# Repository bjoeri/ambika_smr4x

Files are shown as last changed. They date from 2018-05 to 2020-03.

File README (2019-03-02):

SMR4X - Mutated Ambika SMR-4 voice card

SMR4X is a mutation of the original Ambika SMR-4 voice card with an additional mash up of various other design modifications:
- Added programmable 4P/2P filter slope selection (ported from SMR-4-Pi but with added decoupling capacitors for the 4052 and excluding the 1P/3P slopes)
- Added programmable full bandwidth resonance compensation by optional bypass of capacitor in feedback (inspired by Shruthi-1 Sound Designer Edition). NOTE: FOR SOME REASON THIS DOESN'T APPEAR TO MAKE ANY SIGNIFICANT DIFFERENCE, SEE https://forum.mutable-instruments.net/t/another-modified-ambika-smr-4-voice-card/
- Added 50k trimpot and modified related resistor value (from 150k to 120k) to allow for filter tuning (ported from SMR4-Plus)

==============================================
WARNING: THIS IS INCOMPLETE WORKS IN PROGRESS! 
==============================================

SMR4X is released under cc-by-sa 4.0 license.

Original design of the official SMR4 voice card by E. Gillet (pichenettes@mutable-instruments.net).

This design by Björn Somell (bjoeri@gmail.com) relies heavily on the original design, and is inspired by modifications from SMR-4-Pi voice card by Pharmasonic (https://github.com/Pharmasonic/SMR-4-Pi), Shruthi-1 Sound Designer Edition by Martin Walkers (http://mutable-instruments-archive.net/wiki/Shruthi-1_SDE), and SMR4-Plus voice card by Andre Laska (kontakt@tubeohm.com)

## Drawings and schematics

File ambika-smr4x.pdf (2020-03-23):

A

A

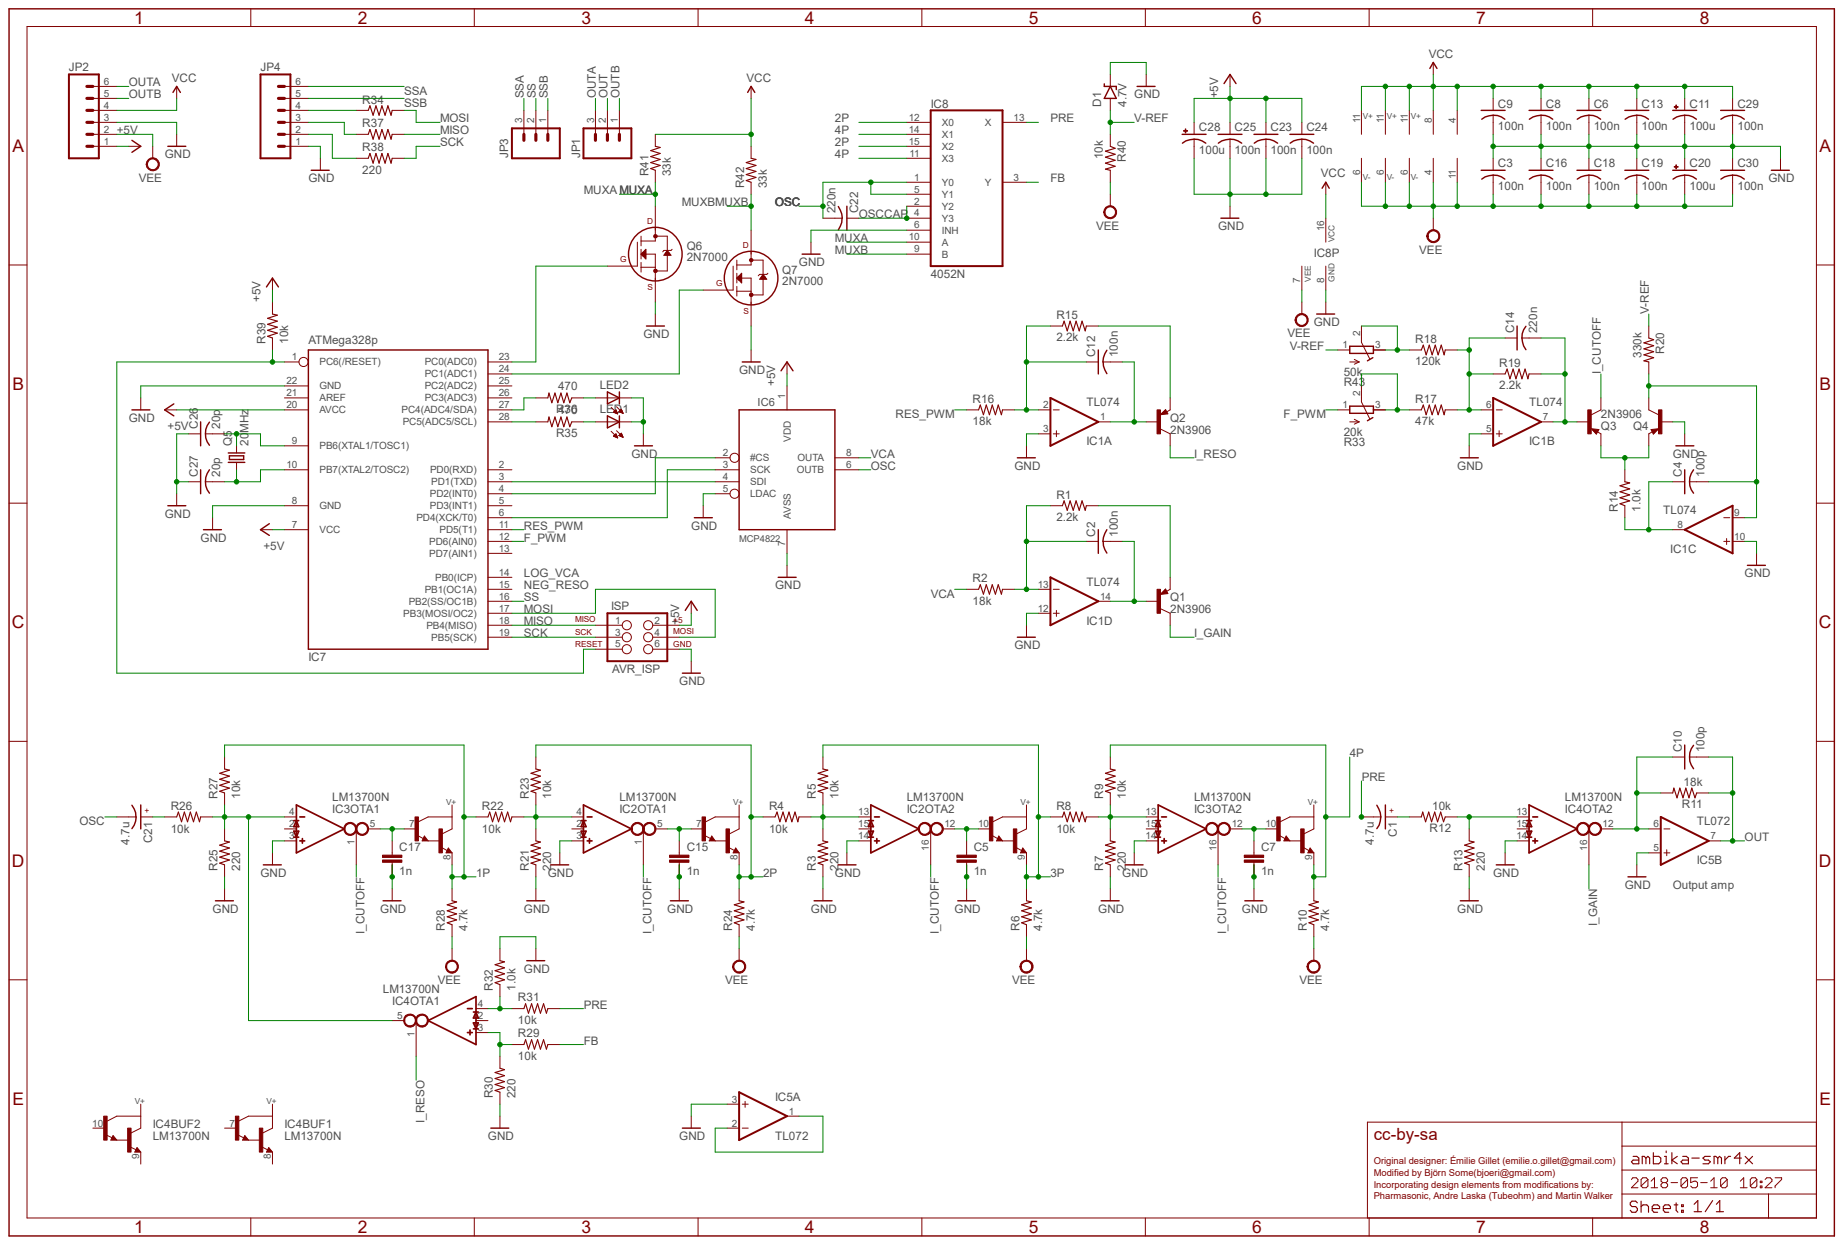
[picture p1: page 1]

MISO | 1 2
SCK | 3 4 | MOSI

RESET | 5 6 | GND

Original designer: Émilie Gillet (emilie.o.gillet@gmail.com)
Modified by Björn Some(bjoeri@gmail.com)
Incorporating design elements from modifications by:
Pharmasonic, Andre Laska (Tubeohm) and Martin Walker

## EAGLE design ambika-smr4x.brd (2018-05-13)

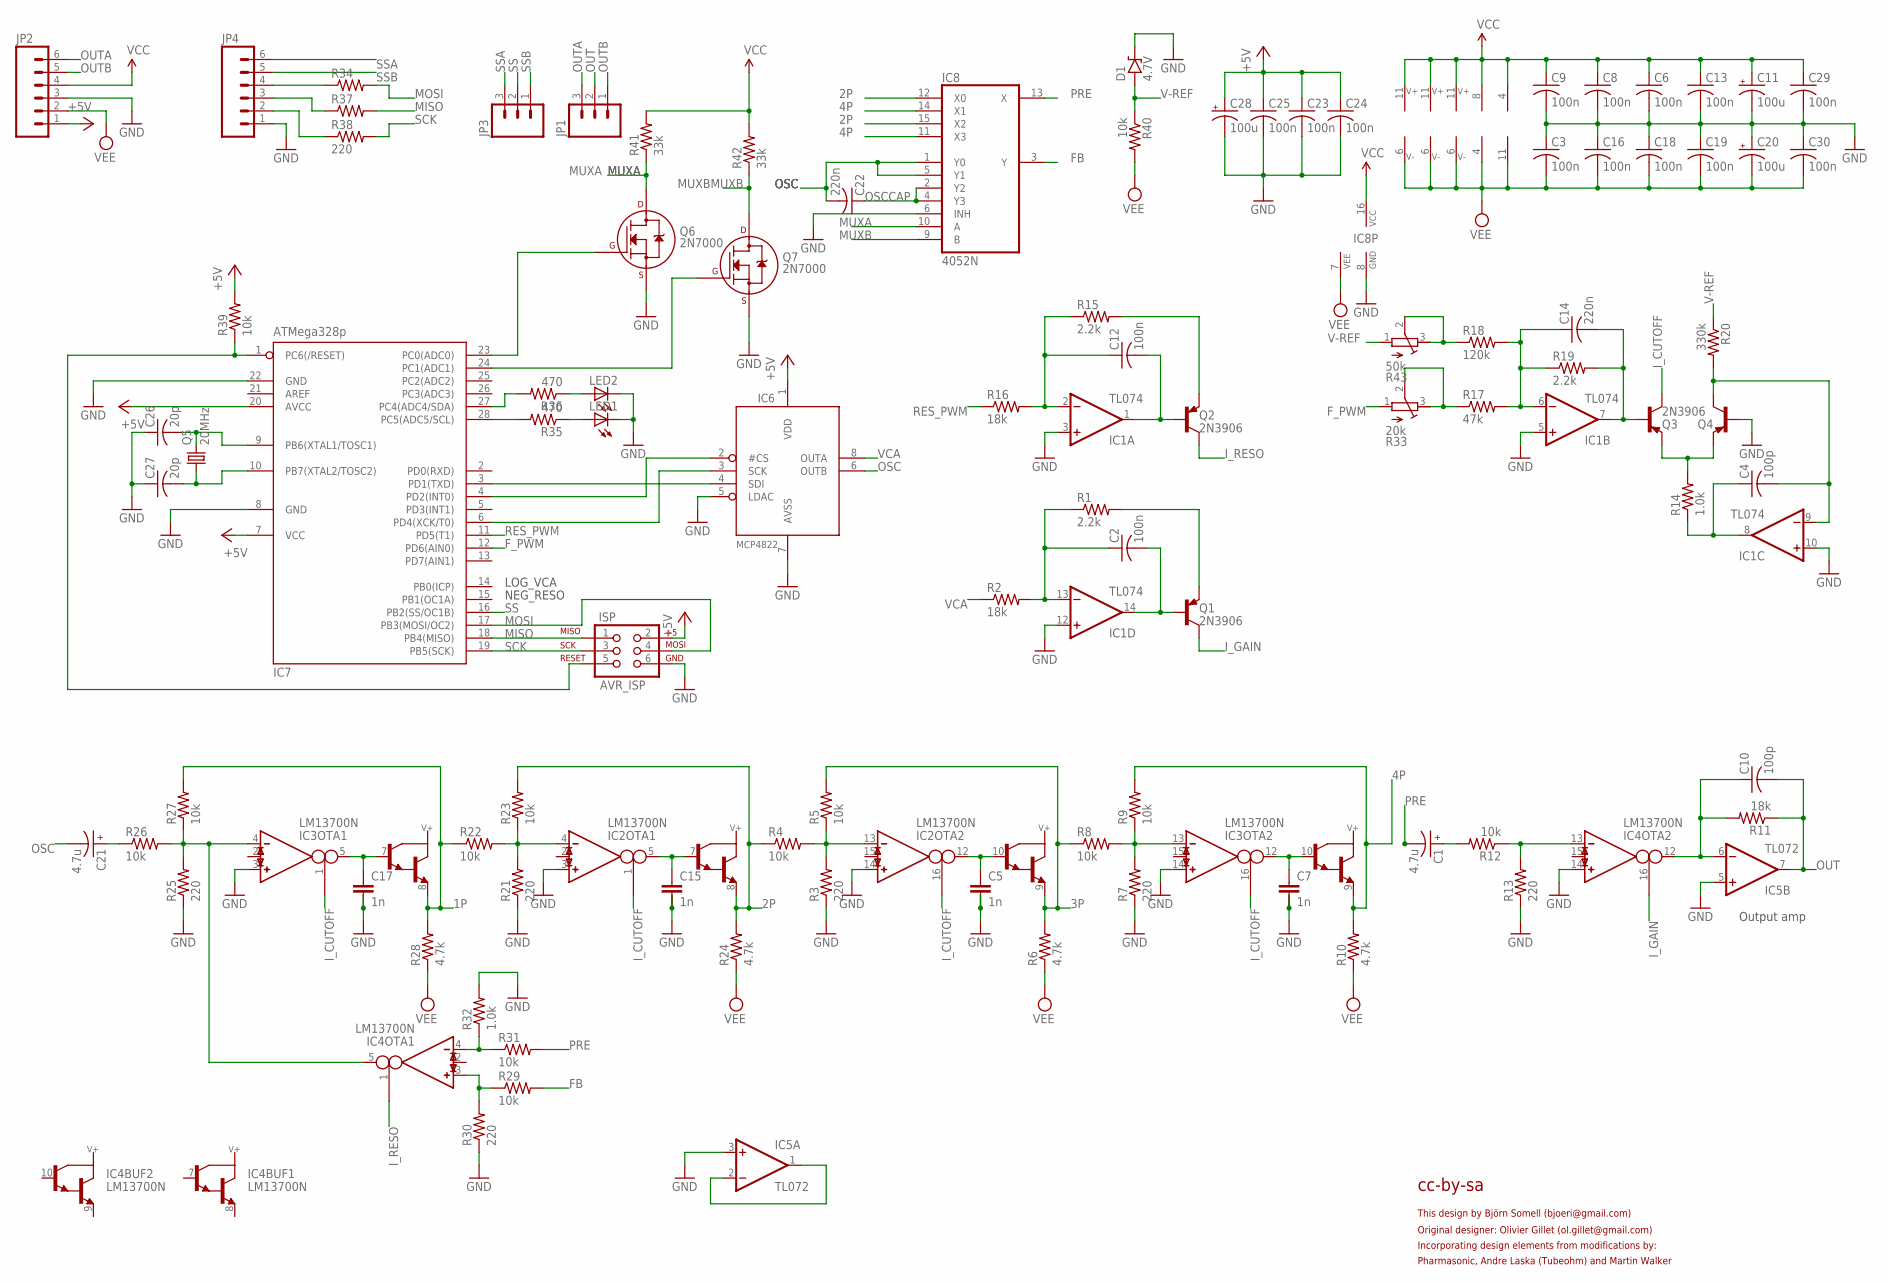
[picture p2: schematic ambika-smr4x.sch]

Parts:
C1, C21: 4.7u; E11-6.3
C2, C3, C6, C8, C9, C12, C13, C16, C18, C19, C23, C24, C29, C30: 100n; C025-025X050
C4, C10: 100p; C025-025X050
C5, C7, C15, C17: 1n; C2.5/5-2
C11, C20, C28: 100u; E2,5-6
C14, C22: 220n; C025-025X050
C25: 100n; C025-024X044
C26, C27: 20p; C025-024X044
D1: 4.7V; D-5
IC1: TL074; DIL14
IC2, IC3, IC4: LM13700N; DIL16
IC5: TL072; DIL08
IC6: MCP4822; DIL08
IC7: ATMega328p; DIL28-3
IC8: 4052N; DIL16
ISP: AVR_ISP; 2X3
JP1, JP3: M03PTH; 1X03
JP2, JP4: M06SIP; 1X06
LED1, LED2: LED3MM
Q1, Q2, Q3, Q4: 2N3906; TO92-
Q5: 20MHz; HC49U-V
Q6, Q7: 2N7000; TO-92
R1, R15, R19: 2.2k; 0204/7
R2, R11, R16: 18k; 0204/7
R3, R7, R13, R21, R25, R30, R34, R37, R38: 220; 0204/7
R4, R5, R8, R9, R12, R22, R23, R26, R27, R29, R31, R39, R40: 10k; 0204/7
R6, R10, R24, R28: 4.7k; 0204/7
R14, R32: 1.0k; 0204/7
R17: 47k; 0204/7
R18: 120k; 0204/7
R20: 330k; 0204/7
R33: 20k; RTRIM3296P
R35, R36: 470; 0204/7
R41, R42: 33k; 0204/7
R43: 50k; RTRIM3296P

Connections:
1P: IC3.8 (E), R22.1, R27.2, R28.2
2P: IC2.8 (E), IC8.12 (X0), IC8.15 (X2), R4.1, R23.2, R24.2
3P: IC2.9 (E), R5.2, R6.2, R8.1
4P: IC3.9 (E), IC8.11 (X3), IC8.14 (X1), R9.2, R10.2
+5V: C23.1, C24.1, C25.1, C28.+, IC6.1 (VDD), IC7.7 (VCC), IC7.20 (AVCC), ISP.2, JP2.1, R39.2
FB: IC8.3 (Y), R29.2
F_PWM: IC7.12 (PD6(AIN0)), R33.1 (E)
GND: C3.1, C5.2, C5.3, C6.2, C7.2, C7.3, C8.2, C9.2, C11.-, C13.2, C15.2, C15.3, C16.1, C17.2, C17.3, C18.1, C19.1, C20.+, C23.2, C24.2, C25.2, C26.1, C27.1, C28.-, C29.2, C30.1, D1.C, IC1.3 (+IN), IC1.5 (+IN), IC1.10 (+IN), IC1.12 (+IN), IC2.3 (IN_P), IC2.14 (IN_P), IC3.3 (IN_P), IC3.14 (IN_P), IC4.14 (IN_P), IC5.3 (+IN), IC5.5 (+IN), IC6.5 (LDAC), IC6.7 (AVSS), IC7.8 (GND), IC7.22 (GND), IC8.6 (INH), IC8.8 (GND), ISP.6, JP2.3, JP4.1, LED1.K (C), LED2.K (C), Q4.2 (B), Q6.1 (S), Q7.1 (S), R3.1, R7.1, R13.1, R21.1, R25.1, R30.1, R32.2
I_CUTOFF: IC2.1 (I_BIAS), IC2.16 (I_BIAS), IC3.1 (I_BIAS), IC3.16 (I_BIAS), Q3.1 (C)
I_GAIN: IC4.16 (I_BIAS), Q1.1 (C)
I_RESO: IC4.1 (I_BIAS), Q2.1 (C)
MISO: IC7.18 (PB4(MISO)), ISP.1, R37.2
MOSI: IC7.17 (PB3(MOSI/OC2)), ISP.4, R34.2
MUXA: IC8.10 (A), Q6.3 (D), R41.1
MUXB: IC8.9 (B), Q7.3 (D), R42.1
unnamed: Q3.3 (E), Q4.3 (E), R14.2
unnamed: C14.2, IC1.7 (OUT), Q3.2 (B), R19.2
unnamed: IC6.4 (SDI), IC7.3 (PD1(TXD))
unnamed: C4.2, IC1.9 (-IN), Q4.1 (C), R20.2
unnamed: C21.+ (1), R26.1
unnamed: R18.1, R43.2 (S), R43.3 (A)
unnamed: LED1.A, R35.1
unnamed: JP4.2, R38.1
unnamed: C4.1, IC1.8 (OUT), R14.1
unnamed: LED2.A, R36.1
unnamed: IC7.27 (PC4(ADC4/SDA)), R36.2
unnamed: IC3.4 (IN_N), IC4.5 (OUT), R25.2, R26.2, R27.1
unnamed: JP4.3, R37.1
unnamed: IC7.1 (PC6(/RESET)), ISP.5, R39.1
unnamed: IC6.3 (SCK), IC7.6 (PD4(XCK/T0))
unnamed: IC6.2 (#CS), IC7.4 (PD2(INT0))
unnamed: IC2.4 (IN_N), R21.2, R22.2, R23.1
unnamed: JP4.4, R34.1
unnamed: C15.1, IC2.5 (OUT), IC2.7 (B)
unnamed: IC7.28 (PC5(ADC5/SCL)), R35.2
unnamed: IC2.13 (IN_N), R3.2, R4.2, R5.1
unnamed: IC5.1 (OUT), IC5.2 (-IN)
unnamed: C5.1, IC2.10 (B), IC2.12 (OUT)
unnamed: IC3.13 (IN_N), R7.2, R8.2, R9.1
unnamed: IC7.23 (PC0(ADC0)), Q6.2 (G)
unnamed: C1.+ (1), R12.2
unnamed: C7.1, IC3.10 (B), IC3.12 (OUT)
unnamed: IC4.4 (IN_N), R31.1, R32.1
unnamed: C12.2, IC1.1 (OUT), Q2.2 (B)
unnamed: C2.2, IC1.14 (OUT), Q1.2 (B)
unnamed: IC4.3 (IN_P), R29.1, R30.2
unnamed: IC4.13 (IN_N), R12.1, R13.2
unnamed: IC7.24 (PC1(ADC1)), Q7.2 (G)
unnamed: C14.1, IC1.6 (-IN), R17.2, R18.2, R19.1
unnamed: R17.1, R33.2 (S), R33.3 (A)
unnamed: C2.1, IC1.13 (-IN), R1.1, R2.2
unnamed: C12.1, IC1.2 (-IN), R15.1, R16.2
unnamed: Q2.3 (E), R15.2
unnamed: C17.1, IC3.5 (OUT), IC3.7 (B)
unnamed: Q1.3 (E), R1.2
unnamed: C10.1, IC4.12 (OUT), IC5.6 (-IN), R11.2
unnamed: C27.2, IC7.10 (PB7(XTAL2/TOSC2)), Q5.1
unnamed: C26.2, IC7.9 (PB6(XTAL1/TOSC1)), Q5.2
OSC: C21.- (2), C22.2, IC6.6 (OUTB), IC8.1 (Y0), IC8.5 (Y1)
OSCCAP: C22.1, IC8.2 (Y2), IC8.4 (Y3)
OUT: C10.2, IC5.7 (OUT), JP1.2, R11.1
OUTA: JP1.3, JP2.6
OUTB: JP1.1, JP2.5
PRE: C1.- (2), IC8.13 (X), R31.2
RES_PWM: IC7.11 (PD5(T1)), R16.1
SCK: IC7.19 (PB5(SCK)), ISP.3, R38.2
SS: IC7.16 (PB2(SS/OC1B)), JP3.2
SSA: JP3.3, JP4.6
SSB: JP3.1, JP4.5
V-REF: D1.A, R20.1, R40.1, R43.1 (E)
VCA: IC6.8 (OUTA), R2.1
VCC: C6.1, C8.1, C9.1, C11.+, C13.1, C29.1, IC1.4 (V+), IC2.11 (V+), IC3.11 (V+), IC4.11 (V+), IC5.8 (V+), IC8.16 (VCC), JP2.4, R41.2, R42.2
VEE: C3.2, C16.2, C18.2, C19.2, C20.-, C30.2, IC1.11 (V-), IC2.6 (V-), IC3.6 (V-), IC4.6 (V-), IC5.4 (V-), IC8.7 (VEE), JP2.2, R6.1, R10.1, R24.1, R28.1, R40.2

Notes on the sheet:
cc-by-sa
This design by Björn Somell (bjoeri@gmail.com)
LOG_VCA
NEG_RESO
Output amp
Original designer: Olivier Gillet (ol.gillet@gmail.com)
Incorporating design elements from modifications by:
Pharmasonic, Andre Laska (Tubeohm) and Martin Walker

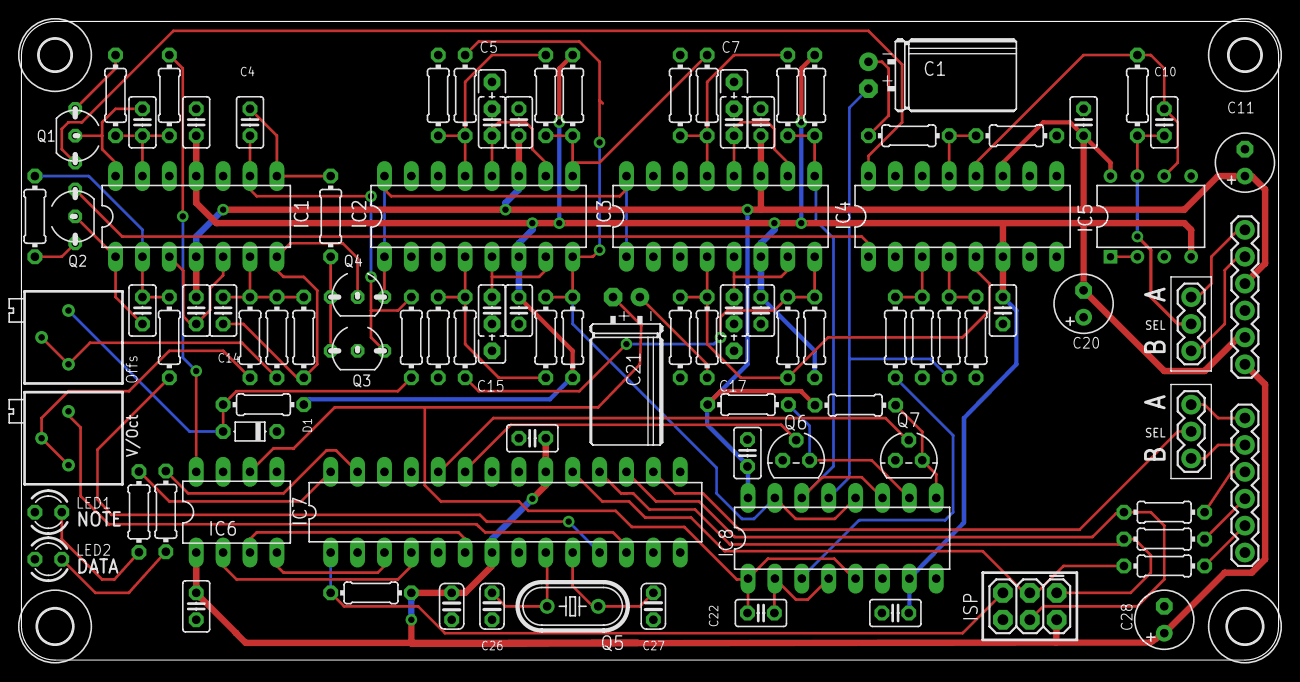
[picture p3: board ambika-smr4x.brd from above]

Board: 2 copper layers, 118.7 x 60.3 mm, 100 parts (0 on the bottom side), 73 nets.

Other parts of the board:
U$1, U$2: 3,0
U$4, U$5: 3,3

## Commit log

2018-05-13 Tidied up board (mainly routing and silkscreen)
    [ambika-smr4x.brd]
2020-03-23 Updated original designer etc info in schematics
    Updated original designer etc info in schematics
